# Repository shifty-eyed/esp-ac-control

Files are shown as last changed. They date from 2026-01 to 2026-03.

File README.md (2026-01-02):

## ESP32 AC Control – WiFi HTTP API + Thermostat Interface

This project controls an AC unit via an **ESP32-WROOM-32** board connected to a **proprietary wall thermostat**.  
The ESP32 exposes a **simple HTTP API** over WiFi and electrically **emulates the thermostat’s ON/OFF button** and **reads the thermostat’s LED status**.

- **HTTP API (port 80)**:
  - **`GET /status`** → returns JSON with AC status, current time, schedules, and webhook URL.
  - **`PUT /on`** → emulates a button press only if AC is currently OFF.
  - **`PUT /off`** → emulates a button press only if AC is currently ON.
  - **`PUT /ha-hook-url?value=<url>`** → configure Home Assistant webhook URL.
  - **`GET /time`** → returns current system time and sync status (JSON).
  - **`PUT /synctime`** → manually trigger NTP time synchronization.
  - **`GET /schedule`** → list all configured schedules (JSON).
  - **`PUT /schedule`** → create or update a schedule.
  - **`DELETE /schedule`** → delete a schedule by ID.
  - **`GET /journal`** → retrieve activity log with timestamps.
  - **`DELETE /journal`** → clear activity log.
  - **`GET /state-journal`** → retrieve AC state change history (CSV format).
  - **`DELETE /state-journal`** → clear state change history.

The project assumes:

- Thermostat **button voltage: 5 V DC**.
- Thermostat **LED sense node: ~0 V on, ~3 V off (DC, measured to thermostat ground)**.
- ESP32 is powered from a **separate 5 V USB power supply**, but **shares ground** with the thermostat electronics.

---

## Framework Choice

The recommended stack for this project is:

- **PlatformIO** (as the build system/IDE).
- **Arduino framework for ESP32**.

**Why Arduino + PlatformIO:**

- Very quick to bring up **WiFi** and an **HTTP server**.
- Lots of reference code and simple APIs (`WiFi.h`, `WebServer.h`).
- Good enough for this relatively small project.

You can later migrate to **ESP-IDF** if you need more control, but Arduino is ideal to get this working fast.

---

## Hardware Overview

- **ESP32 dev board** (e.g. ESP32-WROOM-32 DevKitC).
- **Separate USB 5 V supply** powering the ESP32 dev board.
- **One relay module** (e.g., 1-channel 5V relay module) to emulate the button press.
- Connection to thermostat:
  - **Two button wires** (momentary ON/OFF) - connected via relay contacts.
  - **Two LED wires** (indicating ON/OFF state) - connected to ESP32 GPIO for sensing.

> **Important:** There is **no galvanic isolation** between ESP32 and thermostat in this design.
> The relay provides electrical isolation for the button control, but the LED sense line shares a common ground.
> You accept the risk that sharing ground and interfacing directly may stress the thermostat electronics if its internal design is unusual.

---

## ESP32 Pin Assignment

- **Relay control output (ACTIVE LOW)**:
  - **`GPIO25`** – output (LOW = relay ON = button pressed, HIGH = relay OFF = button released)
- **Thermostat LED sense input (digital)**:
  - **`GPIO32`** – digital input (reads ~3V when AC is ON, ~0V when AC is OFF)

These pins avoid boot-strapping issues and are safe, general-purpose choices on ESP32-WROOM-32.

---

## Power and Grounding

- **ESP32 power:**
  - 5 V from **USB power supply** into ESP32 dev board.
  - The board’s onboard regulator provides **3.3 V** for the ESP32 and GPIO.
- **Thermostat power:**
  - Remains completely on its **own internal supply**.
- **Shared ground (required):**
  - Connect **ESP32 GND** to **thermostat ground**:
    - The thermostat ground is the **LED negative** line and usually one side of the button.

This common ground allows ESP32 GPIO voltages to be correctly referenced to the thermostat signals.

---

## Wiring – Button Emulation with Relay Module

Goal: When ESP32 `GPIO25` goes **LOW**, the relay activates and **closes the button contacts** (in parallel with the physical button), emulating a button press.

### 1. Identify button ground and signal

1. Power the thermostat as normal.
2. With a multimeter:
   - Black probe on the **LED negative** (this is thermostat ground).
   - Red probe on each of the two **button wires**.
3. You should see:
   - One button wire at ≈ **0 V** → this is **button ground side**.
   - The other at some positive voltage (around **5 V**) or varying when pressed → **button signal side**.

Keep the physical button connected; we simply add the relay contacts **in parallel**.

### 2. Relay module wiring

Use a standard **1-channel 5V relay module** (commonly available with opto-isolated input).

**Relay Module Connections:**

- **VCC** (relay module power):
  - Connect to **ESP32 5V** (VIN pin on dev board, powered from USB).

- **GND** (relay module ground):
  - Connect to **ESP32 GND**.

- **IN** (relay control signal):
  - Connect to **ESP32 `GPIO25`**.
  - Most relay modules are **ACTIVE LOW**: when GPIO25 is LOW, relay activates.

**Relay Contacts (to thermostat button):**

- **COM** (common terminal):
  - Connect to **button ground side** (the wire that measured ~0V).

- **NO** (normally open terminal):
  - Connect to **button signal side** (the wire that measured ~5V).

**Shared Ground:**

- Connect **thermostat ground** (LED negative wire) to **ESP32 GND**.
  - This common ground reference is necessary for the LED sense circuit to work correctly.

### How it works

- When `GPIO25` is **HIGH** → relay is **off**, button contacts are **open**, button behaves normally.
- When `GPIO25` is **LOW** → relay **activates**, NO contact **closes** to COM, **shorting the button signal to ground**, emulating a button press.

The ESP32 code drives GPIO25 LOW for 300ms to emulate a button press, then returns it HIGH to release.

---

## Wiring – LED Status to ESP32 (Digital Input)
TBD

### LED sense wiring (digital)
TBD

The 10 kΩ resistor limits current and provides protection for the GPIO pin.

## Software Sketch Outline (Arduino + PlatformIO)

This section intentionally left open so you can keep the software implementation in code files  
(`main.cpp`, etc.) rather than embedding it in the README.

---

## PlatformIO Quick Start

1. **Create project** in PlatformIO:
   - Board: **`esp32dev`** (or your specific ESP32 DevKit).
   - Framework: **Arduino**.
2. Implement your logic in `src/main.cpp` using the wiring and API description above.
3. Set your **WiFi credentials** in your code (`ssid` / `password` or similar).
4. Connect the ESP32 via USB.
5. In PlatformIO:
   - **Build** → **Upload** → **Monitor**.
6. Once running, note the **IP address** printed over serial.

Test from a PC on the same network:

```bash
# Check AC status (returns JSON with status, time, schedules, webhook URL)
curl http://<esp-ip>/status

# Turn AC on
curl -X PUT http://<esp-ip>/on

# Turn AC off
curl -X PUT http://<esp-ip>/off

# Configure Home Assistant webhook
curl -X PUT "http://<esp-ip>/ha-hook-url?value=http://<ha-ip>:8123/api/webhook/<webhook-id>"

# Create/update a schedule (turn AC on at 7:30 AM)
curl -X PUT "http://<esp-ip>/schedule?id=0&hour=7&minute=30&switch=1"

# Delete a schedule
curl -X DELETE "http://<esp-ip>/schedule?id=0"

# View activity journal
curl http://<esp-ip>/journal

# View state change history (CSV)
curl http://<esp-ip>/state-journal

# Clear journals
curl -X DELETE http://<esp-ip>/journal
curl -X DELETE http://<esp-ip>/state-journal
```

---

## Time Synchronization and Scheduling

The system includes **NTP time synchronization** and **persistent schedule management** to automatically control the AC at specific times.

### Time Synchronization

- **NTP Server**: `pool.ntp.org`
- **Timezone**: GMT-5 (Eastern US) – configurable in code
- **Sync Mode**: Manual only (no automatic re-sync)
- Initial sync attempted on boot; device continues to work even if sync fails

#### Time API Endpoints

**GET /time** – Get current system time

```bash
curl http://<esp-ip>/time
```

Response:
```json
{"time": "2025-11-25 14:30:00", "synced": true}
```

**PUT /synctime** – Manually trigger NTP sync

```bash
curl -X PUT http://<esp-ip>/synctime
```

Response:
```json
{"status": "syncing"}
```

### Schedule Management

Up to **16 schedules** (IDs 0-15) are stored persistently in **NVS (Non-Volatile Storage)** and survive ESP32 reboots.

Each schedule specifies:
- **id**: Schedule slot (0-15)
- **hour**: Hour of day (0-23)
- **minute**: Minute of hour (0-59)
- **switch**: Desired AC state (1 = turn on, 0 = turn off)

The system checks schedules every loop iteration and automatically triggers the AC when the scheduled time is reached.

#### Schedule API Endpoints

**GET /schedule** – List all schedules

```bash
curl http://<esp-ip>/schedule
```

Response:
```json
[
  {"id": 0, "hour": 7, "minute": 30, "switch": 1},
  {"id": 1, "hour": 22, "minute": 0, "switch": 0}
]
```

**PUT /schedule** – Create or update a schedule

```bash
# Turn AC ON at 7:30 AM
curl -X PUT "http://192.168.4.120/schedule?id=0&hour=7&minute=30&switch=1"

# Turn AC OFF at 10:00 PM (22:00)
curl -X PUT "http://192.168.4.120/schedule?id=1&hour=22&minute=0&switch=0"

```

Response:
```json
{"status": "ok", "id": 0}
```

**DELETE /schedule** – Delete a schedule

```bash
curl -X DELETE "http://<esp-ip>/schedule?id=0"
```

Response:
```json
{"status": "deleted", "id": 0}
```

#### Parameter Validation

- **id**: Must be 0-15
- **hour**: Must be 0-23 (24-hour format)
- **minute**: Must be 0-59
- **switch**: Must be 0 (off) or 1 (on)

Invalid parameters return HTTP 400 with error details in JSON.

### Schedule Behavior

- Schedules are checked every loop iteration (≈2ms)
- When a schedule time is reached, the system:
  1. Checks current AC state
  2. If AC is already in desired state, no action is taken
  3. If AC needs to change state, a button press is emulated
- Each schedule triggers only once per minute (prevents duplicate execution)
- Schedules persist through reboots via NVS storage

---

## Home Assistant Integration

The system includes **webhook integration** to automatically notify Home Assistant whenever the AC state changes.

### Configuring the Webhook

Set the Home Assistant webhook URL using the `/ha-hook-url` endpoint:

```bash
curl -X PUT "http://<esp-ip>/ha-hook-url?value=http://<ha-ip>:8123/api/webhook/<webhook-id>"
```

**Example:**
```bash
curl -X PUT "http://192.168.4.120/ha-hook-url?value=http://192.168.4.199:8123/api/webhook/ac_status_main"
```

The webhook URL is stored persistently in NVS and survives ESP32 reboots.

### Webhook Behavior

The ESP32 automatically sends an HTTP POST request to the configured webhook URL whenever the AC state changes:

- **When triggered:**
  - Manual API control via `/on` or `/off` endpoints
  - Scheduled events (when a schedule triggers a state change)
  - External state changes detected (someone uses the physical thermostat button)

- **Payload format (JSON):**
  ```json
  {"status":"on"}
  ```
  or
  ```json
  {"status":"off"}
  ```

- **HTTP timeout:** 5 seconds
- **Logging:** All webhook attempts are logged to the activity journal with HTTP response codes

### Checking Current Configuration

The configured webhook URL is included in the `/status` endpoint response:

```bash
curl http://<esp-ip>/status
```

Response includes:
```json
{
  "status": "1",
  "time": "2025-12-29 10:30:00",
  "schedules": [...],
  "ha_webhook": "http://192.168.4.199:8123/api/webhook/ac_status_main"
}
```

---

## External State Change Detection

The system continuously monitors the AC state to detect **external changes** that occur outside of the ESP32's control, such as someone manually pressing the physical thermostat button.

### How It Works

- **Monitoring interval:** Every 5 seconds
- **Detection method:** Compares current AC state (read from LED) against the last known state
- **Actions when external change detected:**
  1. Updates the internal state tracker
  2. Logs the state change to the state journal
  3. Sends a webhook notification to Home Assistant (if configured)

### Use Cases

- **Track manual overrides:** Know when someone uses the physical thermostat instead of the API
- **Synchronize state:** Keep Home Assistant and other systems synchronized even when the thermostat is manually controlled
- **Debugging:** Identify unexpected state changes or thermostat behavior
- **Analytics:** Build a complete history of all AC state changes regardless of source

### Example

If you turn on the AC using `/on`, the system knows it initiated the change. But if someone walks up and presses the physical button, the external state change detection will:
- Detect the change within 5 seconds
- Log it: `[2025-12-29 14:32:15] External state change detected`
- Record the timestamp and new state in the state journal
- Notify Home Assistant via webhook

This ensures complete visibility into all AC state changes, whether controlled by the API, schedules, or manual button presses.

---

## Activity Logging (Journal System)

The system includes two types of journals for tracking activity and debugging:

### 1. Activity Journal

A **circular buffer** that stores the most recent **200 events** with timestamps.

**What it logs:**
- Manual API requests (`/on`, `/off`)
- Schedule triggers and results
- Webhook POST attempts and HTTP response codes
- Configuration changes (webhook URL updates)
- External state changes detected

**Format:**
```
[YYYY-MM-DD HH:MM:SS] message
```

**Example output:**
```
[2025-12-29 07:30:00] Schedule #0 triggered: Turn ON
[2025-12-29 07:30:01] Schedule #0 result: Success from 0 retry
[2025-12-29 07:30:02] HA webhook: on -> HTTP 200
[2025-12-29 14:15:23] Manual turn OFF requested
[2025-12-29 14:15:24] Manual turn OFF result: Already there
```

**API Endpoints:**

```bash
# View activity journal
curl http://<esp-ip>/journal

# Clear activity journal
curl -X DELETE http://<esp-ip>/journal
```

### 2. State Journal

A **linear buffer** that stores up to **3000 state change records** for long-term analytics.

**What it logs:**
- Every AC state transition (ON→OFF or OFF→ON)
- Includes both API-initiated and externally-detected changes

**Format (CSV):**
```
timestamp,state
```

Where:
- `timestamp` = Unix timestamp (seconds since epoch)
- `state` = `1` (AC on) or `0` (AC off)

**Example output:**
```
1735473000,1
1735480200,0
1735494600,1
```

**API Endpoints:**

```bash
# View state journal (CSV format)
curl http://<esp-ip>/state-journal

# Clear state journal
curl -X DELETE http://<esp-ip>/state-journal
```

### Use Cases

- **Debugging:** Trace exactly what happened and when
- **Analytics:** Export state journal CSV for analysis (uptime statistics, usage patterns, etc.)
- **Monitoring:** Check recent activity via journal endpoint
- **Troubleshooting:** Identify why a schedule didn't trigger or why a state change failed

The activity journal is useful for real-time debugging with human-readable messages, while the state journal provides raw data perfect for importing into spreadsheets or data analysis tools.

---

## Safety Notes

- Double-check **voltages** with a multimeter before final wiring.
- Verify that the **thermostat ground point** you tie to ESP32 GND is correct and stable.
- Start with **short test pulses** and monitor for any unusual thermostat behavior (reboots, flicker, etc.).
- If at any point the thermostat behaves erratically, consider switching to a **relay or optocoupler-based design** for full isolation.

---

With this wiring and setup, you get a **simple WiFi-controlled AC switch** that mirrors the existing wall thermostat’s logic and state via a clean HTTP API.

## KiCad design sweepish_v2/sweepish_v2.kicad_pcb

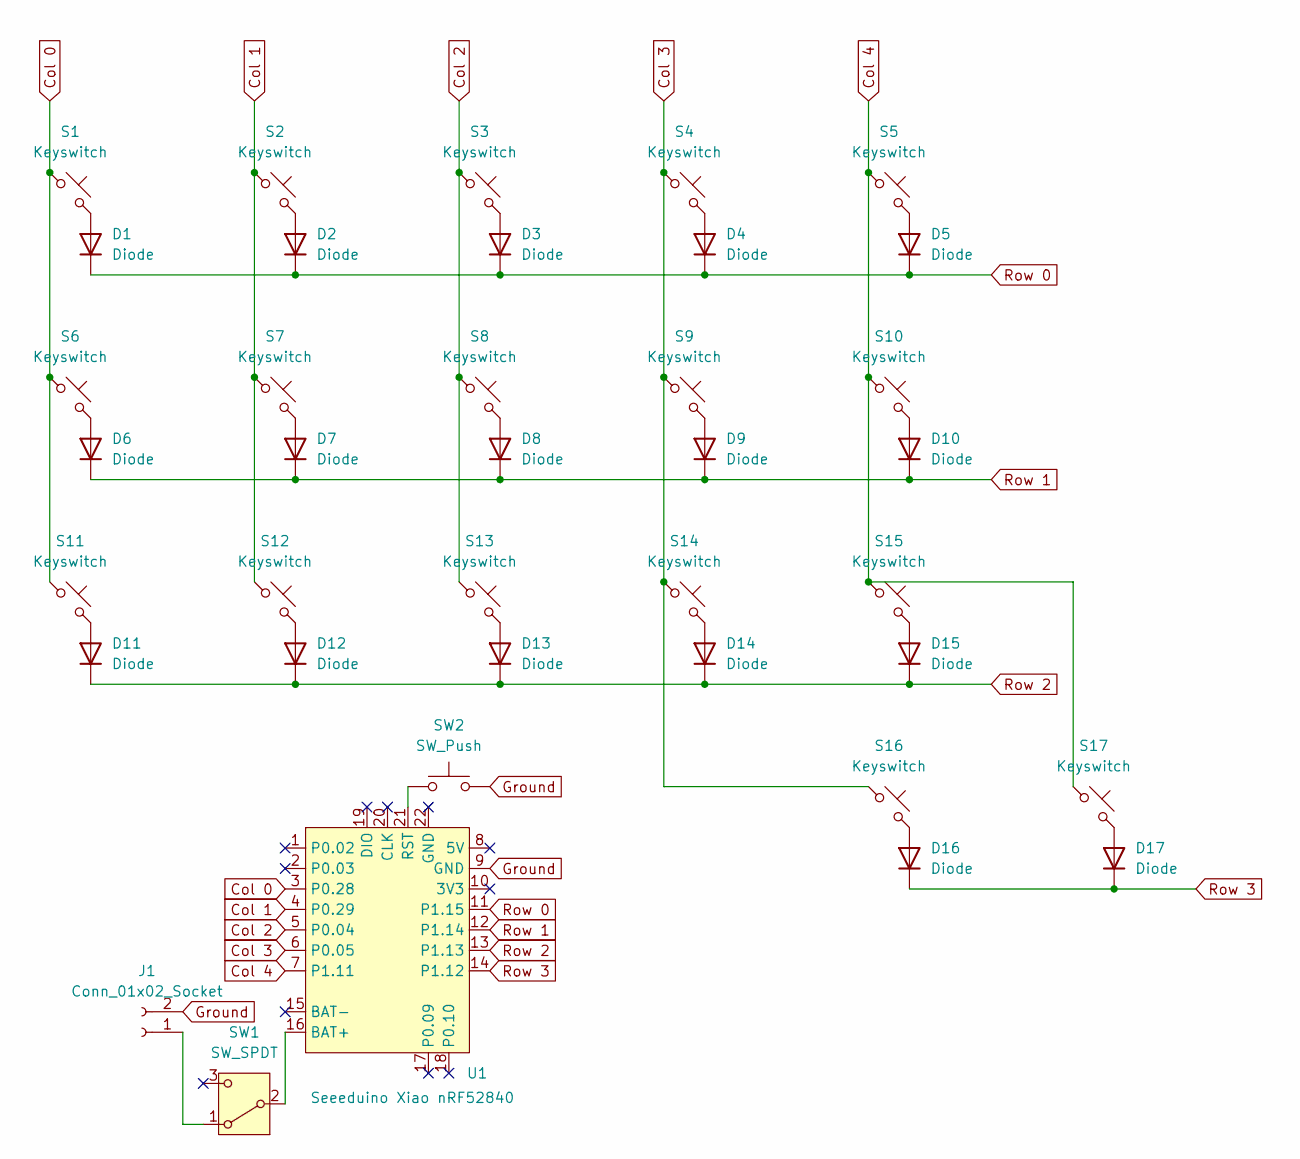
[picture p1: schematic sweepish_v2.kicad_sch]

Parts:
D1, D2, D3, D4, D5, D6, D7, D8, D9, D10, D11, D12, D13, D14, D15, D16, D17: Diode; Diode_SOD-123
J1: Conn_01x02_Socket; JST_PH_S2B-PH-SM4-TB_1x02-1MP_P2.00mm_Horizontal
S1, S2, S3, S4, S5, S6, S7, S8, S9, S10, S11, S12, S13, S14, S15, S16, S17: Keyswitch; Choc_V1_1.00u
SW1: SW_SPDT; SW_MSK12C02-HB
SW2: SW_Push; SW_T1A2QR
U1: Seeeduino Xiao nRF52840; Xiao_nRF52840_AC_Reflow

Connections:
Col 0: S1.1, S6.1, S11.1, U1.3 (P0.28)
Col 1: S2.1, S7.1, S12.1, U1.4 (P0.29)
Col 2: S3.1, S8.1, S13.1, U1.5 (P0.04)
Col 3: S4.1, S9.1, S14.1, S16.1, U1.6 (P0.05)
Col 4: S5.1, S10.1, S15.1, S17.1, U1.7 (P1.11)
Ground: J1.2, SW2.2, U1.9 (GND)
unnamed: D1.2 (A), S1.2
unnamed: D2.2 (A), S2.2
unnamed: D3.2 (A), S3.2
unnamed: D4.2 (A), S4.2
unnamed: D5.2 (A), S5.2
unnamed: D6.2 (A), S6.2
unnamed: D7.2 (A), S7.2
unnamed: D8.2 (A), S8.2
unnamed: D9.2 (A), S9.2
unnamed: D10.2 (A), S10.2
unnamed: D11.2 (A), S11.2
unnamed: D12.2 (A), S12.2
unnamed: D13.2 (A), S13.2
unnamed: D14.2 (A), S14.2
unnamed: D15.2 (A), S15.2
unnamed: D16.2 (A), S16.2
unnamed: D17.2 (A), S17.2
unnamed: J1.1, SW1.1 (A)
unnamed: SW1.2 (B), U1.16 (BAT+)
unnamed: SW2.1, U1.21 (RST)
Row 0: D1.1 (K), D2.1 (K), D3.1 (K), D4.1 (K), D5.1 (K), U1.11 (P1.15)
Row 1: D6.1 (K), D7.1 (K), D8.1 (K), D9.1 (K), D10.1 (K), U1.12 (P1.14)
Row 2: D11.1 (K), D12.1 (K), D13.1 (K), D14.1 (K), D15.1 (K), U1.13 (P1.13)
Row 3: D16.1 (K), D17.1 (K), U1.14 (P1.12)

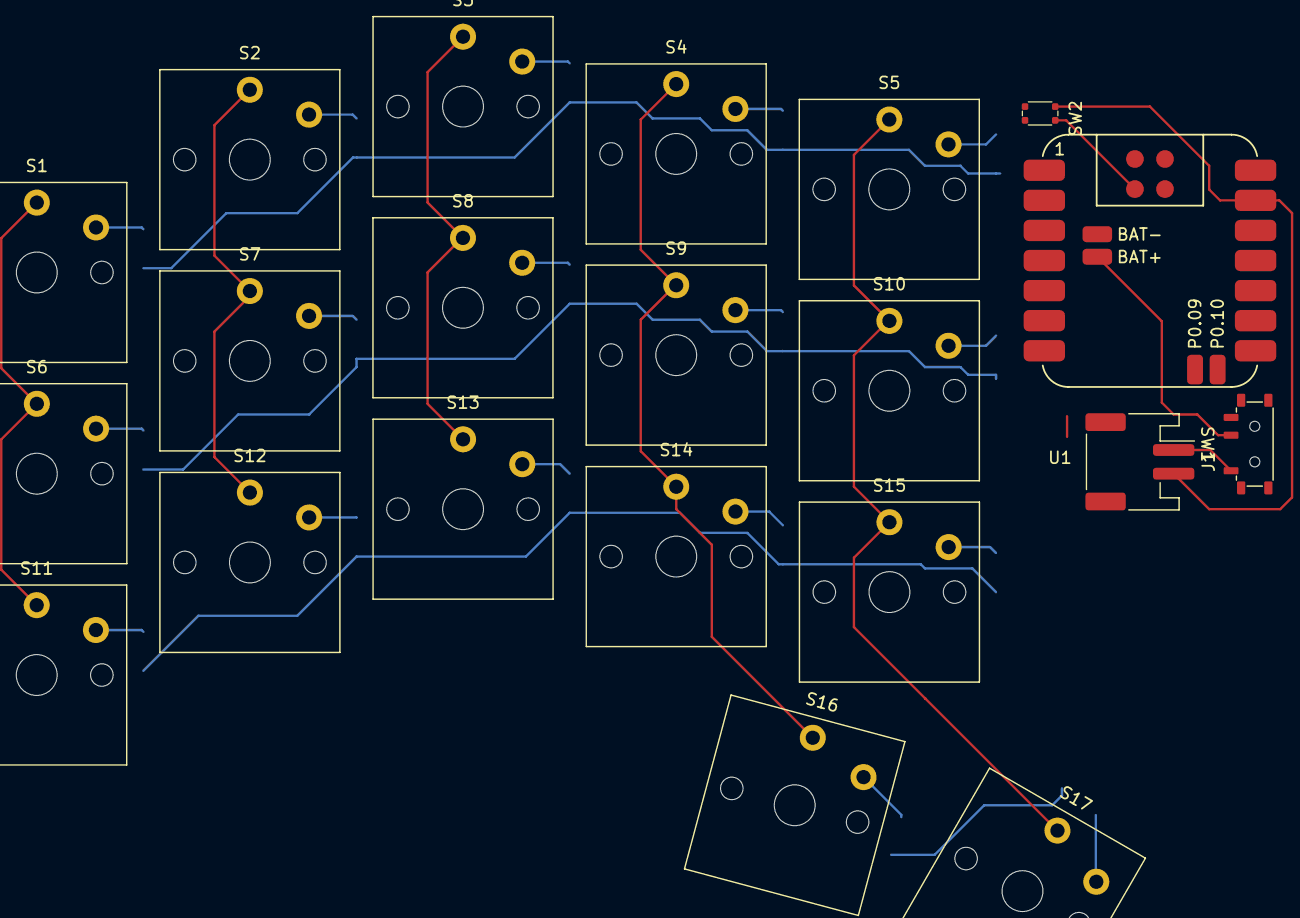
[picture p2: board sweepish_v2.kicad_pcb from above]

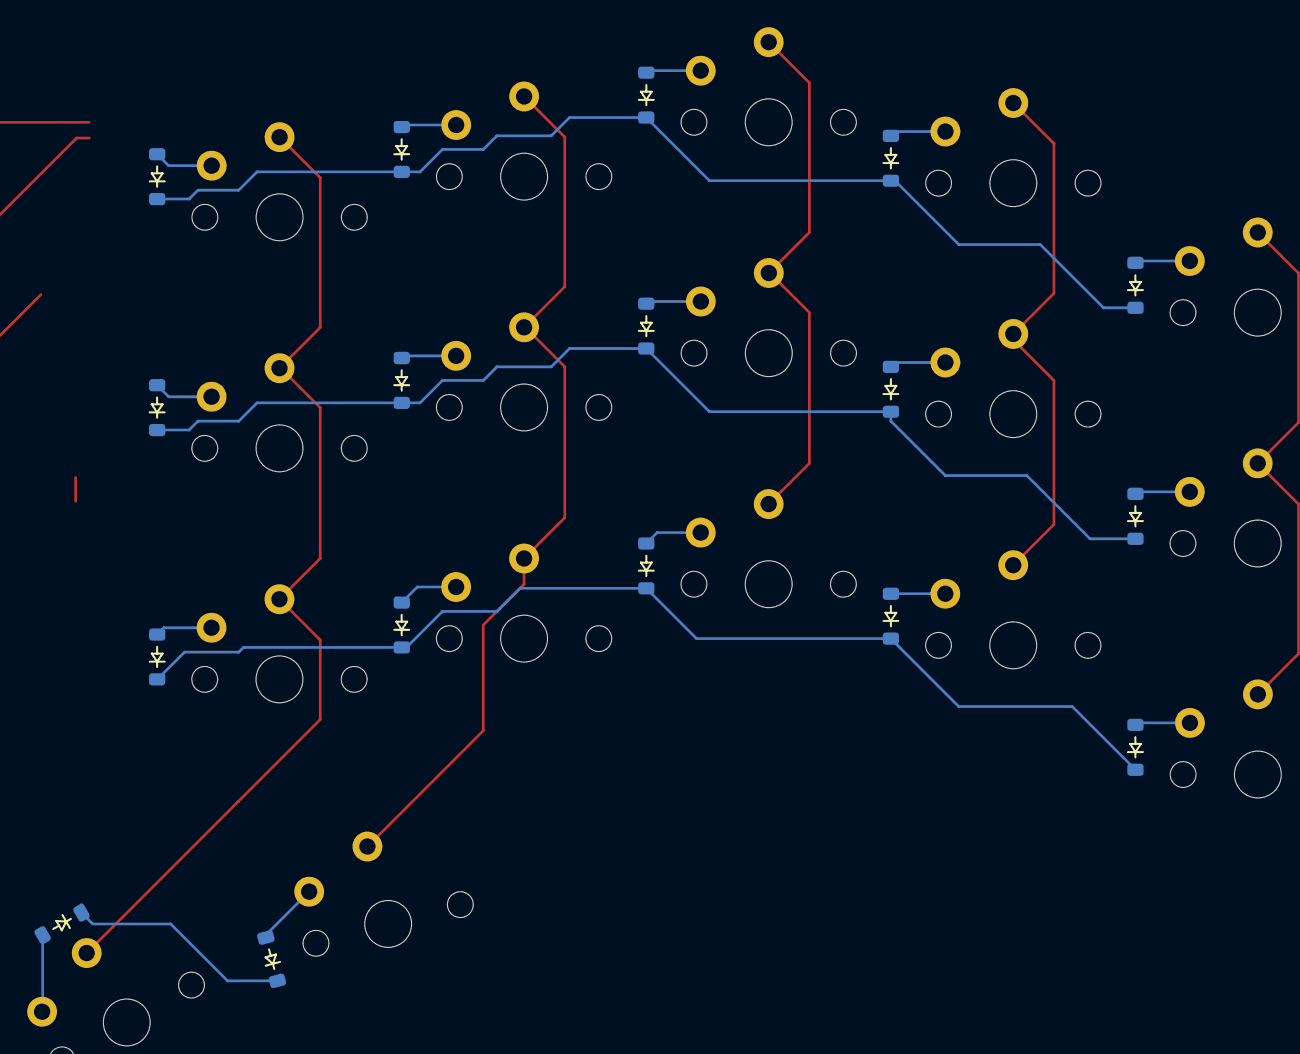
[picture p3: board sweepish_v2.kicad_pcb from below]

Board: 2 copper layers, 38 parts (17 on the bottom side), 30 nets.

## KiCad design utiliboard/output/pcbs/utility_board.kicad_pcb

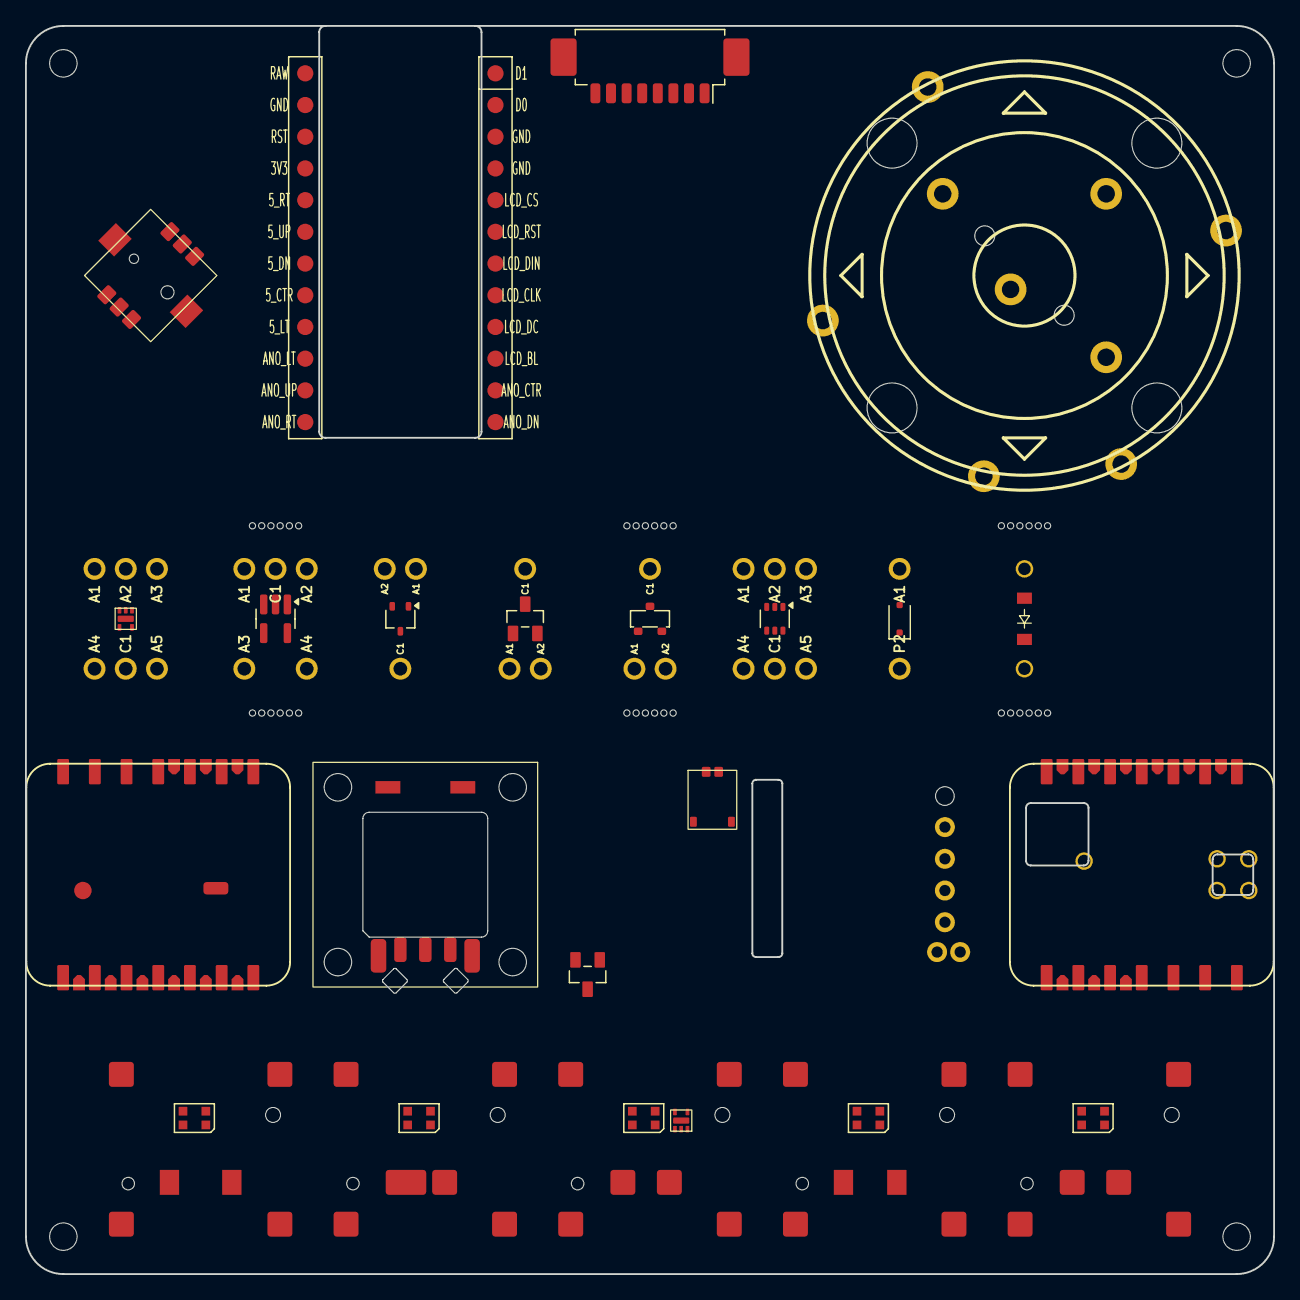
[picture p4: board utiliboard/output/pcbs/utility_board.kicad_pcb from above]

Board: 2 copper layers, 100.0 x 100.0 mm, 47 parts (0 on the bottom side), 76 nets, no tracks yet.

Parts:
CONN1: Molex_PicoBlade_53261-0871_1x08-1MP_P1.25mm_Horizontal
CONN2: Molex_Pico_EZMate_Plus_1x02
D1, D7: D_MMBD4148PLM
D2, D6: BAV70; BAV70 SOT23
D3: SOT-23
D4: D_SOD-323F
D5: diode_tht_sod123
H1, H2: mounting_hole_plated
LED1, LED2, LED3, LED4, LED5: LED_WS2812B-2020_PLCC4_2.0x2.0mm
MCU1: mcu_nice_nano
MDS1: SKRHADE010_naked
MH1, MH2, MH3, MH4: mounting_hole_npth
RE1: ENCODER_ANO
RE2: CKW12
S2, S3, S4, S5, S6: PG1316S
XX1, XX2, XX3, XX4, XX5, XX6: mousebites 2mm; mousebites_25mm
XX7, XX9, XX11, XX12, XX13, XX15, XX16: 5diode_Breakout_Holes
XX8: SC-74A-5_1.55x2.9mm_P0.95mm
XX10: SOT-323_SC-70
XX14: SOT-363_SC-70-6
XX17, XX18: xiao_plus_smd_prod

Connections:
1A1: D1.1, XX7.1
1A2: D1.2, XX7.2
1A3: D1.3, XX7.3
1A4: D1.4, XX7.4
1A5: D1.5, XX7.6
1C1: D1.6, XX7.5
2A1: XX8.1, XX9.3
2A2: XX8.3, XX9.1
2A3: XX8.4, XX9.4
2A4: XX8.5, XX9.5
2C1: XX8.2, XX9.2
3P1: XX10.1, XX11.1
3P2: XX10.2, XX11.2
3P3: XX10.3, XX11.3
3V3: CONN1.1, MCU1.21, XX17.12, XX18.12
4A1: D2.1, XX12.1
4A2: D2.2, XX12.2
4C1: D2.3, XX12.3
5A1: D3.1, XX13.1
5A2: D3.2, XX13.2
5C1: D3.3, XX13.3
5V: LED1.4, LED2.4, LED3.4, LED4.4, LED5.4, XX17.14, XX18.14
5_CTR: MCU1.17, MDS1.2
5_DN: MCU1.18, MDS1.3
5_LT: MCU1.16, MDS1.1
5_RT: MCU1.20, MDS1.6
5_UP: MCU1.19, MDS1.4
6P1: XX14.1, XX15.3
6P2: XX14.2, XX15.2
6P3: XX14.3, XX15.1
6P4: XX14.4, XX15.4
6P5: XX14.5, XX15.5
6P6: XX14.6, XX15.6
7P1: D4.2, XX16.1
7P2: D4.1, XX16.2
ANO_B: RE1.A, RE1.B
ANO_CTR: MCU1.11, RE1.S1
ANO_DN: MCU1.12, RE1.S2
ANO_LT: MCU1.15, RE1.S5
ANO_RT: MCU1.13, RE1.S3
ANO_UP: MCU1.14, RE1.S4
C0: RE2.S1, S2.1, XX17.19, XX18.19
C1: S3.1, XX17.6, XX18.6
C2: S4.1, XX17.21, XX18.21
C3: S5.1, XX17.9, XX18.9
C4: S6.1, XX17.22, XX18.22
GND: CONN1.2, CONN2.1, LED1.2, LED2.2, LED3.2, LED4.2, LED5.2, MCU1.3, MCU1.4, MCU1.23, MDS1.5, RE1.COM_A, RE1.COM_B, RE2.B, S3.3, S4.3, S5.3, S6.3, XX17.13, XX18.13, XX18.27
LCD_BL: CONN1.8, MCU1.10
LCD_CLK: CONN1.4, MCU1.8
LCD_CS: CONN1.5, MCU1.5
LCD_DC: CONN1.6, MCU1.9
LCD_DIN: CONN1.3, MCU1.7
LCD_RST: CONN1.7, MCU1.6
P0.02: XX17.1, XX18.1
P0.03: XX17.2, XX18.2
P0.15: XX17.15, XX18.15
P0.19: XX17.16, XX18.16
P0.28: XX17.3, XX18.3
P0.29: XX17.4, XX18.4
P0.31: XX17.20, XX18.20
P1.01: XX17.17, XX18.17
P1.15: XX17.11, XX18.11
R0: D7.6, XX17.7, XX18.7
R1: D6.3, XX17.8, XX18.8
RAW: CONN2.2, MCU1.24, XX17.28, XX18.28
RST: MCU1.22, XX17.26, XX18.26
ckw12_to: D6.1, RE2.S2
ckw_a: XX17.10, XX18.10
ckw_b: XX17.23, XX18.23
index_home: D7.1, S5.2
inner_home: D7.4, S6.2
middle_home: D7.2, S4.2
pinky_home: D7.5, S2.2
ring_home: D7.3, S3.2
scroll_a: XX17.18, XX18.18
scroll_b: XX17.5, XX18.5

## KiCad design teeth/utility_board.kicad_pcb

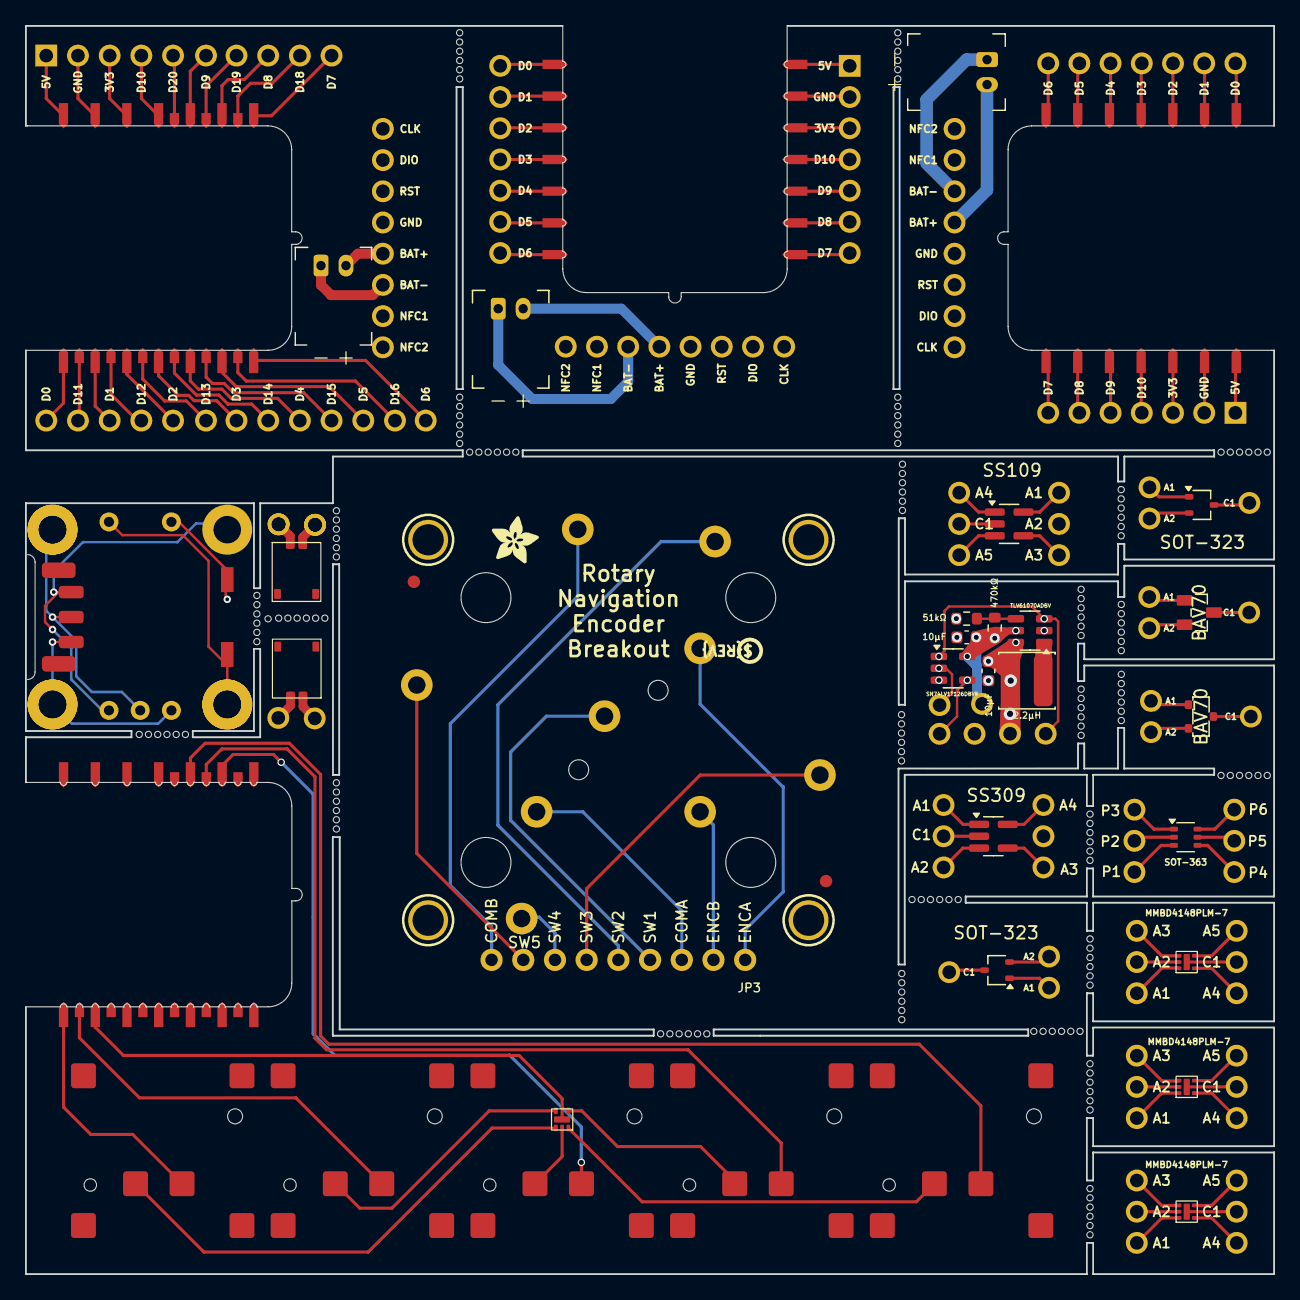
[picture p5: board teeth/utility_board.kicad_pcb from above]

Board: 2 copper layers, 100.1 x 100.0 mm, 54 parts (1 on the bottom side), 107 nets.

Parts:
C1, C2: 10μF; C_0603_1608Metric
CONN1, CONN1#2: Battery Connector; Molex_Pico_EZMate_Plus_1x02
D1, D2, D3, D8: D_MMBD4148PLM
D5: SOT-23
D6: BAV70; BAV70 SOT23
FID3, FID4: FIDUCIAL_1MM
J1, J2#2, J3, J4#2: xiao_plus_cutout
J1#2, J2, J3#2, J4: Conn_01x01_Pin; my_mount_hole_M2_pad
JP3: 1X09_ROUND_70
JST1, JST1#2, JST1#3: battery_connector_jst_ph_2
L1: 2.2μH; L_CJIANG_FTC404030S_4.1x4.1x3.0_SMD
MCU1, MCU2, MCU3: XIAO_Breakout_Holes
R1: 470kΩ; R_0603_1608Metric
R2: 51kΩ; R_0603_1608Metric
S1, S3, S5, S7, S9: PG1316S_Square_Pads
U1: TLV61070ADBV; SOT-23-6
U2: SN74LV1T126DBVR; SOT-23-5
U$25, U$27, U$29, U$30: MOUNTINGHOLE2.5; MOUNTINGHOLE_2.5_PLATED
U$32: ADAFRUIT_3.5MM
U$33: PCBFEAT-REV-040
X1: ENCODER_ANO
XX17, XX18, XX18#2, XX19, XX19#2, XX19#3, XX21, XX21#2, XX21#3, XX22: 5diode_Breakout_Holes

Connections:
1A1: D1.1, XX17.1
1A2: D1.2, XX17.2
1A3: D1.3, XX17.3
1A4: D1.4, XX17.4
1A5: D1.5, XX17.5
1C1: D1.6, XX17.6
2A1: D2.1, XX18.1
2A2: D2.2, XX18.2
2A3: D2.3, XX18.3
2A4: D2.4, XX18.4
2A5: D2.5, XX18.5
2C1: D2.6, XX18.6
3A1: D3.1, XX19.1
3A2: D3.2, XX19.2
3A3: D3.3, XX19.3
3A4: D3.4, XX19.4
3A5: D3.5, XX19.5
3C1: D3.6, XX19.6
3V3_a: J2#2.12, MCU1.12
3V3_b: J3.12, MCU2.12
3V3_c: J4#2.12, MCU3.12
5A1: D5.1, XX21#3.1
5A2: D5.2, XX21#3.2
5C1: D5.3, XX21#3.3
5V: C2.1, J1.14, R1.1, U1.5 (V_{OUT}), U2.5 (VCC)
5V_EN: U1.3 (EN), U2.1
5V_a: J2#2.14, MCU1.14
5V_b: J3.14, MCU2.14
5V_c: J4#2.14, MCU3.14
6A1: D6.1, XX22.1
6A2: D6.2, XX22.2
6C1: D6.3, XX22.3
BAT-: JST1#2.1, MCU1.29
BAT_a: CONN1.2, CONN1#2.2, JST1#2.2, MCU1.28
BOOST_FB: R1.2, R2.1, U1.4 (V_{FB})
BOOST_SW: L1.2, U1.1 (SW)
COMA: JP3.3, X1.COM_A
COMB: JP3.9, X1.COM_B
D0_a: J2#2.1, MCU1.1
D0_b: J3.1, MCU2.1
D0_c: J4#2.1, MCU3.1
D1_a: J2#2.2, MCU1.2
D1_b: J3.2, MCU2.2
D1_c: J4#2.2, MCU3.2
D2_a: J2#2.3, MCU1.3
D2_b: J3.3, MCU2.3
D2_c: J4#2.3, MCU3.3
D3_a: J2#2.4, MCU1.4
D3_b: J3.4, MCU2.4
D3_c: J4#2.4, MCU3.4
D4_a: J2#2.5, MCU1.5
D4_b: J3.5, MCU2.5
D4_c: J4#2.5, MCU3.5
D5_a: J2#2.6, MCU1.6
D5_b: J3.6, MCU2.6
D5_c: J4#2.6, MCU3.6
D6_a: J2#2.7, MCU1.7
D6_b: J3.7, MCU2.7
D6_c: J4#2.7, MCU3.7
D7_a: J2#2.8, MCU1.8
D7_b: J3.8, MCU2.8
D7_c: J4#2.8, MCU3.8
D8_a: J2#2.9, MCU1.9
D8_b: J3.9, MCU2.9
D8_c: J4#2.9, MCU3.9
D9_a: J2#2.10, MCU1.10
D9_b: J3.10, MCU2.10
D9_c: J4#2.10, MCU3.10
D10_a: J2#2.11, MCU1.11
D10_b: J3.11, MCU2.11
D10_c: J4#2.11, MCU3.11
D11_a: J2#2.15, MCU1.15
D12_a: J2#2.16, MCU1.16
D13_a: J2#2.17, MCU1.17
D14_a: J2#2.18, MCU1.18
D15_a: J2#2.19, MCU1.19
D15_b: JST1#3.2, MCU2.19
D15_c: JST1.2, MCU3.19
D16_a: J2#2.20, MCU1.20
D16_b: JST1#3.1, MCU2.20
D16_c: JST1.1, MCU3.20
D17_a: J2#2.21, MCU1.21
D18_a: J2#2.22, MCU1.22
D19_a: J2#2.23, MCU1.23
ENC_A: JP3.1, X1.A
ENC_B: JP3.2, X1.B
GND: C1.2, C2.2, CONN1.1, CONN1#2.1, J1.13, R2.2, U1.2 (GND), U2.3 (GND), XX19#2.6, XX19#3.2
GND_a: J2#2.13, MCU1.13
GND_b: J3.13, MCU2.13
GND_c: J4#2.13, MCU3.13
P0.02: J1.1, S1.2
P0.03: D8.6, J1.2
P0.15: J1.15, S3.2
P1.05: J1.22, S7.2
P1.13: J1.9, S5.2
P1.14: J1.10, S9.2
RAW: C1.1, L1.1, U1.6 (V_{IN})
SW1: JP3.4, X1.S1
SW2: JP3.5, X1.S2
SW3: JP3.6, X1.S3
SW4: JP3.7, X1.S4
SW5: JP3.8, X1.S5
index_home: D8.4, S7.1
inner_home: D8.1, S9.1
middle_home: D8.2, S5.1
pinky_home: D8.3, S1.1
ring_home: D8.5, S3.1

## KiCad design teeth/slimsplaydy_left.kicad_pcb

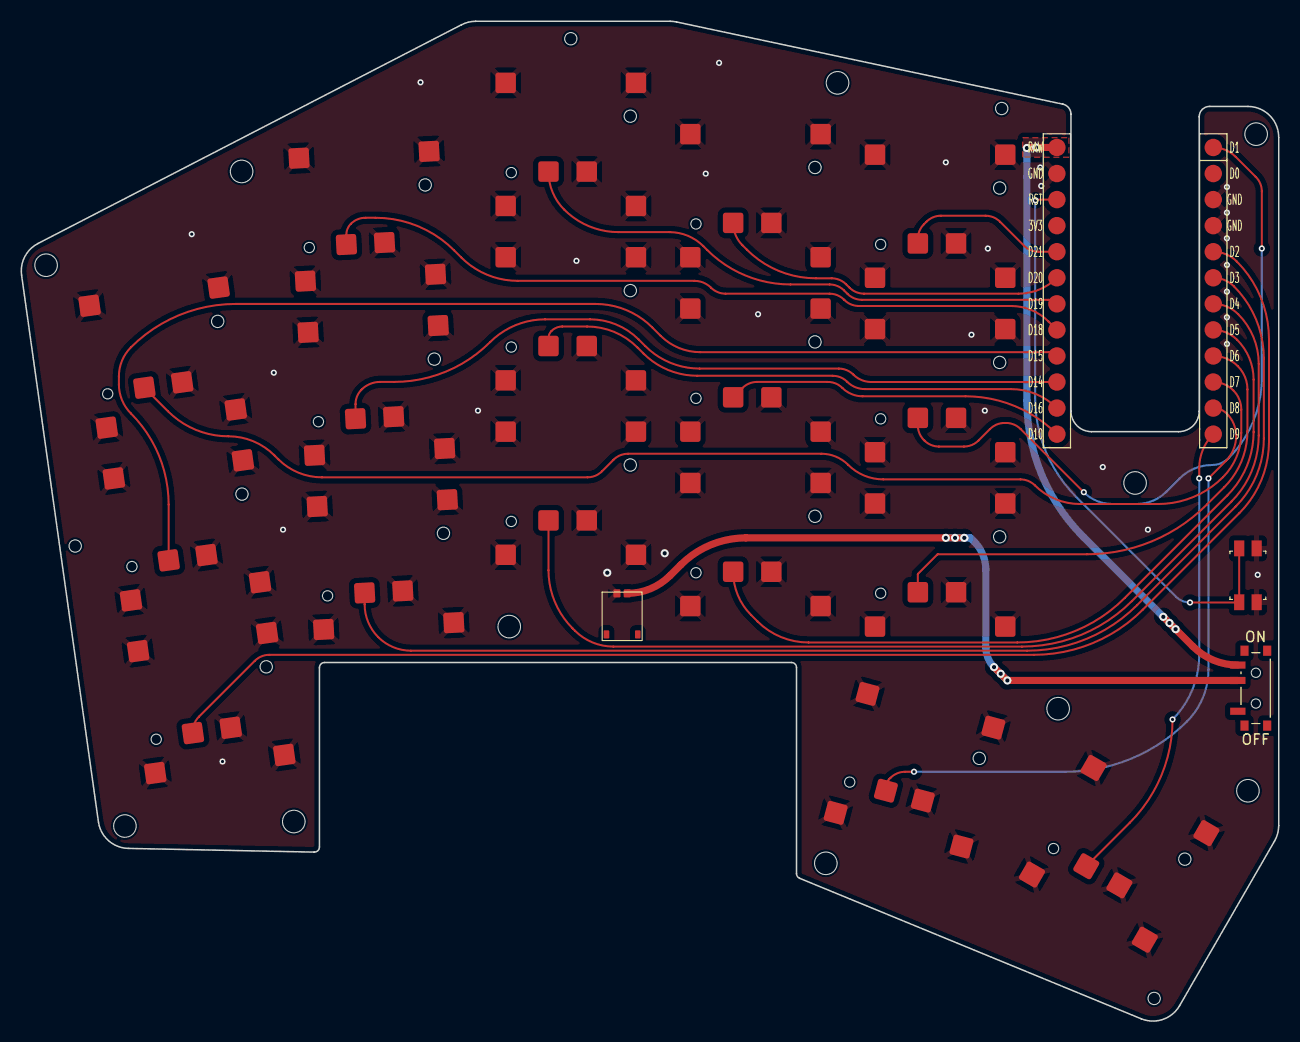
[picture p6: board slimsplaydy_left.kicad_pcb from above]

Board: 2 copper layers, 122.6 x 97.5 mm, 37 parts (1 on the bottom side), 21 nets.

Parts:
CONN1: Battery Connector; Molex_Pico_EZMate_Plus_1x02
MAG1: magsafe
MCU1: nice_nano; mcu_nice_nano
MH1, MH2, MH3, MH4, MH5, MH6, MH7, MH8, MH9, MH10, MH11, MH12, MH13, MH14, MH15: mounting_hole_npth
PWR1: Power SW; power_switch_smd_side
RST1: Reset SW; reset_switch_smd_side
S1, S2, S3, S4, S5, S6, S7, S8, S9, S10, S11, S12, S13, S14, S15, S16, S17: PG1316S

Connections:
BAT_P: CONN1.2, PWR1.2 (B)
GND: CONN1.1, MCU1.3 (GND), MCU1.4 (GND), MCU1.23 (GND), RST1.1, RST1.3, S1.2, S1.3 (B), S2.2, S2.3 (B), S3.2, S3.3 (B), S4.2, S4.3 (B), S5.2, S5.3 (B), S6.2, S6.3 (B), S7.2, S7.3 (B), S8.2, S8.3 (B), S9.2, S9.3 (B), S10.2, S10.3 (B), S11.2, S11.3 (B), S12.2, S12.3 (B), S13.2, S13.3 (B), S14.2, S14.3 (B), S15.2, S15.3 (B), S16.2, S16.3 (B), S17.2, S17.3 (B)
RAW: MCU1.24 (BAT+), PWR1.3 (C)
RST: MCU1.22 (RST), RST1.2, RST1.4
finger_index_bottom: MCU1.8 (P0.24), S10.1
finger_index_home: MCU1.13 (P0.09-LF), S11.1
finger_index_top: MCU1.19 (P0.29-LF), S12.1
finger_inner_bottom: MCU1.9 (P1.00), S13.1
finger_inner_home: MCU1.1 (P0.06), S14.1
finger_inner_top: MCU1.20 (P0.31-LF), S15.1
finger_middle_bottom: MCU1.7 (P0.22), S7.1
finger_middle_home: MCU1.14 (P0.10-LF), S8.1
finger_middle_top: MCU1.18 (P0.02-LF), S9.1
finger_pinky_bottom: MCU1.5 (P0.17), S1.1
finger_pinky_home: MCU1.16 (P1.13-LF), S2.1
finger_pinky_top: MCU1.10 (P0.11), S3.1
finger_ring_bottom: MCU1.6 (P0.20), S4.1
finger_ring_home: MCU1.15 (P1.11-LF), S5.1
finger_ring_top: MCU1.17 (P1.15-LF), S6.1
thumb_reachy_fan: MCU1.12 (P1.06-LF), S17.1
thumb_tucky_fan: MCU1.11 (P1.04-LF), S16.1

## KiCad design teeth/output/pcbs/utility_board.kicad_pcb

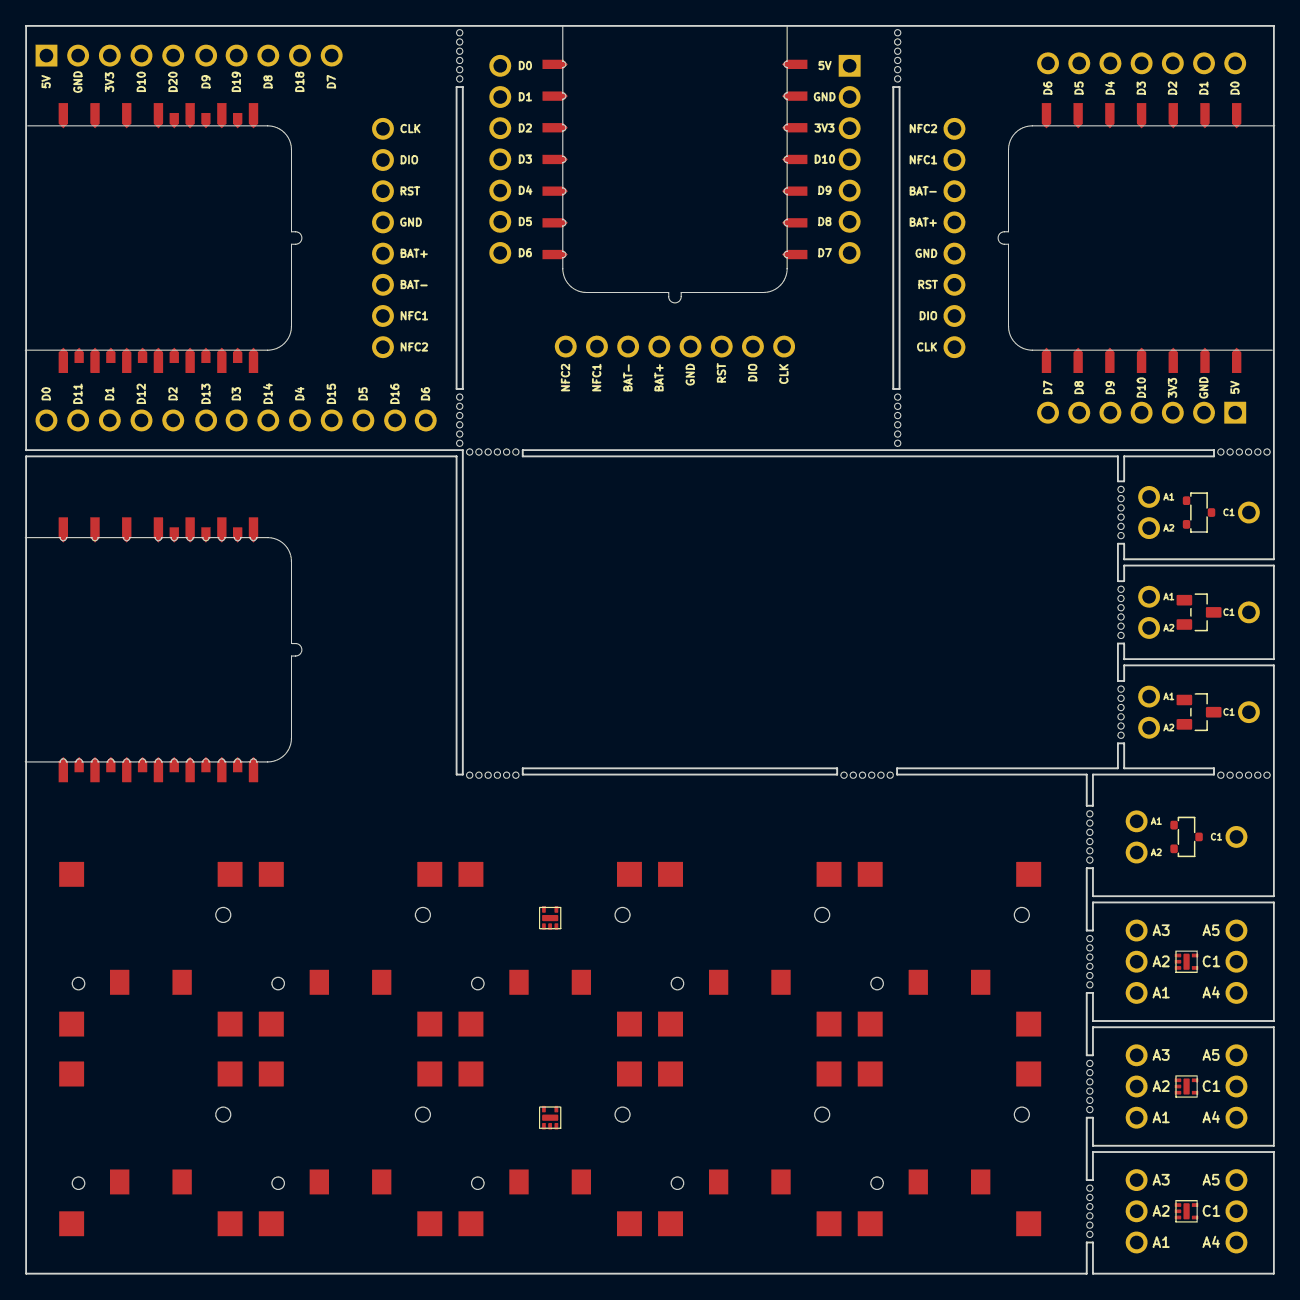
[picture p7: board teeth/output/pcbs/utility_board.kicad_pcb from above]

Board: 2 copper layers, 100.0 x 100.0 mm, 49 parts (0 on the bottom side), 98 nets, no tracks yet.

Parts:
D1, D2, D3, D8, D9: D_MMBD4148PLM
D4, D6: BAV70; BAV70 SOT23
D5, D7: SOT-23
J1, J2, J3, J4: xiao_plus_cutout
MCU1, MCU2, MCU3: XIAO_Breakout_Holes
S1, S2, S3, S4, S5, S6, S7, S8, S9, S10: CPG1316S01D02_mikeholscher
XX1, XX2, XX3, XX4, XX5, XX6, XX7, XX8, XX9, XX10, XX11, XX12, XX13, XX14, XX15, XX16: mousebites 2mm; mousebites_25mm
XX17, XX18, XX19, XX20, XX21, XX22, XX23: 5diode_Breakout_Holes

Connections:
1A1: D1.1, XX17.1
1A2: D1.2, XX17.2
1A3: D1.3, XX17.3
1A4: D1.4, XX17.4
1A5: D1.5, XX17.5
1C1: D1.6, XX17.6
2A1: D2.1, XX18.1
2A2: D2.2, XX18.2
2A3: D2.3, XX18.3
2A4: D2.4, XX18.4
2A5: D2.5, XX18.5
2C1: D2.6, XX18.6
3A1: D3.1, XX19.1
3A2: D3.2, XX19.2
3A3: D3.3, XX19.3
3A4: D3.4, XX19.4
3A5: D3.5, XX19.5
3C1: D3.6, XX19.6
3V3_a: J2.12, MCU1.12
3V3_b: J3.12, MCU2.12
3V3_c: J4.12, MCU3.12
4A1: D4.1, XX20.1
4A2: D4.2, XX20.2
4C1: D4.3, XX20.3
5A1: D5.1, XX21.1
5A2: D5.2, XX21.2
5C1: D5.3, XX21.3
5V_a: J2.14, MCU1.14
5V_b: J3.14, MCU2.14
5V_c: J4.14, MCU3.14
6A1: D6.1, XX22.1
6A2: D6.2, XX22.2
6C1: D6.3, XX22.3
7A1: D7.1, XX23.1
7A2: D7.2, XX23.2
7C1: D7.3, XX23.3
D0_a: J2.1, MCU1.1
D0_b: J3.1, MCU2.1
D0_c: J4.1, MCU3.1
D1_a: J2.2, MCU1.2
D1_b: J3.2, MCU2.2
D1_c: J4.2, MCU3.2
D2_a: J2.3, MCU1.3
D2_b: J3.3, MCU2.3
D2_c: J4.3, MCU3.3
D3_a: J2.4, MCU1.4
D3_b: J3.4, MCU2.4
D3_c: J4.4, MCU3.4
D4_a: J2.5, MCU1.5
D4_b: J3.5, MCU2.5
D4_c: J4.5, MCU3.5
D5_a: J2.6, MCU1.6
D5_b: J3.6, MCU2.6
D5_c: J4.6, MCU3.6
D6_a: J2.7, MCU1.7
D6_b: J3.7, MCU2.7
D6_c: J4.7, MCU3.7
D7_a: J2.8, MCU1.8
D7_b: J3.8, MCU2.8
D7_c: J4.8, MCU3.8
D8_a: J2.9, MCU1.9
D8_b: J3.9, MCU2.9
D8_c: J4.9, MCU3.9
D9_a: J2.10, MCU1.10
D9_b: J3.10, MCU2.10
D9_c: J4.10, MCU3.10
D10_a: J2.11, MCU1.11
D10_b: J3.11, MCU2.11
D10_c: J4.11, MCU3.11
D11_a: J2.15, MCU1.15
D12_a: J2.16, MCU1.16
D13_a: J2.17, MCU1.17
D14_a: J2.18, MCU1.18
D15_a: J2.19, MCU1.19
D16_a: J2.20, MCU1.20
D17_a: J2.21, MCU1.21
D18_a: J2.22, MCU1.22
D19_a: J2.23, MCU1.23
GND_a: J2.13, MCU1.13
GND_b: J3.13, MCU2.13
GND_c: J4.13, MCU3.13
P0.02: J1.1, S1.2, S2.2
P0.03: D8.6, J1.2
P0.15: J1.15, S3.2, S4.2
P1.03: D9.6, J1.21
P1.05: J1.22, S7.2, S8.2
P1.13: J1.9, S5.2, S6.2
P1.14: J1.10, S9.2, S10.2
index_home: D8.1, S7.1
index_top: D9.1, S8.1
inner_home: D8.4, S9.1
inner_top: D9.4, S10.1
middle_home: D8.2, S5.1
middle_top: D9.2, S6.1
pinky_home: D8.5, S1.1
pinky_top: D9.5, S2.1
ring_home: D8.3, S3.1
ring_top: D9.3, S4.1

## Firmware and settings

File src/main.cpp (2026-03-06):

/*
 * ESP32 AC Control - WiFi HTTP API for Thermostat Interface
 * 
 * Hardware connections:
 *   - GPIO25: Relay control (ACTIVE LOW - LOW=ON, HIGH=OFF)
 *   - GPIO32: LED sense input (digital read, 3V when AC on, 0V when off)
 *   - VIN: Relay module power
 *   - GND: Shared ground
 * 
 * HTTP API:
 *   GET  /status  → returns "1" (AC on) or "0" (AC off)
 *   PUT  /on      → turns AC on if currently off
 *   PUT  /off     → turns AC off if currently on
 */

#include <Arduino.h>
#include <WiFi.h>
#include <WebServer.h>
#include <HTTPClient.h>
#include <time.h>
#include <esp_sntp.h>
#include <Preferences.h>

#include "LedSense.h"

// Time configuration
const char* NTP_SERVER = "pool.ntp.org";
const long  GMT_OFFSET_SEC = -5 * 3600;      // GMT-5 (Eastern US)
const int   DAYLIGHT_OFFSET_SEC = 0;

// Schedule structure
struct Schedule {
  int id;
  int hour;
  int minute;
  int switchState;  // 1 = turn on, 0 = turn off
  bool executed;
  bool valid;       // true if schedule slot is populated
};

Schedule schedules[16];
Preferences preferences;
String haWebhookUrl = "";

bool lastKnownAcState = false;
unsigned long lastStateCheckMillis = 0;
const unsigned long STATE_CHECK_INTERVAL = 5000;

unsigned long lastWiFiCheckMillis = 0;
const unsigned long WIFI_CHECK_INTERVAL = 30000;

// Journal (in-memory log)
const int JOURNAL_MAX_LINES = 200;
String journal[JOURNAL_MAX_LINES];
int journalCount = 0;
int journalIndex = 0;  // Circular buffer index

struct StateChangeRecord {
  unsigned long timestamp;
  bool state;
};

const int STATE_JOURNAL_MAX_RECORDS = 3000;
StateChangeRecord stateJournal[STATE_JOURNAL_MAX_RECORDS];
int stateJournalCount = 0;

const char* WIFI_SSID     = "imenilenina-bistro";
const char* WIFI_PASSWORD = "10101010";

const int HTTP_PORT = 80;

const int BUTTON_PIN    = 25;
const int LED_SENSE_PIN = 32;

const int BUTTON_PRESS_DURATION = 300;

WebServer server(HTTP_PORT);

// LED sense is encapsulated to keep signal filtering/polarity isolated.
static LedSense ledSence;

static inline bool isAcOn() {
  return ledSence.isOn();
}

// ========== Journal Functions ==========

void addToJournal(String message) {
  struct tm timeinfo;
  String timestamp;

  if (getLocalTime(&timeinfo)) {
    char timeStr[20];
    strftime(timeStr, sizeof(timeStr), "%Y-%m-%d %H:%M:%S", &timeinfo);
    timestamp = String(timeStr);
  } else {
    timestamp = "NO-TIME";
  }

  journal[journalIndex] = "[" + timestamp + "] " + message;
  journalIndex = (journalIndex + 1) % JOURNAL_MAX_LINES;

  if (journalCount < JOURNAL_MAX_LINES) {
    journalCount++;
  }

  Serial.println("[JOURNAL] " + message);
}

void clearJournal() {
  journalCount = 0;
  journalIndex = 0;
  Serial.println("[JOURNAL] Cleared");
}

void addToStateJournal(bool state) {
  struct tm timeinfo;
  unsigned long timestamp = 0;

  if (getLocalTime(&timeinfo)) {
    timestamp = mktime(&timeinfo);
  }

  stateJournal[stateJournalCount].timestamp = timestamp;
  stateJournal[stateJournalCount].state = state;
  if (stateJournalCount < STATE_JOURNAL_MAX_RECORDS - 1) {
    stateJournalCount++;
  }
}

void clearStateJournal() {
  stateJournalCount = 0;
}

void initGPIO() {
  pinMode(BUTTON_PIN, OUTPUT);
  digitalWrite(BUTTON_PIN, LOW); 
  pinMode(LED_SENSE_PIN, INPUT_PULLUP);
}

void sendHomeAssistantWebhook(bool acState) {
  if (haWebhookUrl == "" || haWebhookUrl.length() == 0) {
    return;
  }
  if (WiFi.status() != WL_CONNECTED) {
    addToJournal("HA webhook skipped: WiFi not connected");
    return;
  }

  HTTPClient http;
  http.begin(haWebhookUrl);
  http.addHeader("Content-Type", "application/json");
  http.setTimeout(5000);

  String payload = "{\"status\":\"" + String(acState ? "on" : "off") + "\"}";

  int httpCode = http.POST(payload);

  String logMsg = "HA webhook: " + String(acState ? "on" : "off");
  if (httpCode > 0) {
    logMsg += " -> HTTP " + String(httpCode);
  } else {
    logMsg += " -> FAILED: " + http.errorToString(httpCode);
  }
  addToJournal(logMsg);

  http.end();
}

String setOn(bool desiredState) {
  const int maxAttempts = 5;
  for (int attempt = 0; attempt < maxAttempts; attempt++) {
    if (isAcOn() == desiredState) {
      if (attempt == 0) {
        return "Already there\n";
      } else {
        return "Success from " + String(attempt) + " retry\n";
      }
    }

    digitalWrite(BUTTON_PIN, HIGH);
    ledSence.wait(BUTTON_PRESS_DURATION);
    digitalWrite(BUTTON_PIN, LOW);
    ledSence.wait(500);
    if (isAcOn() != desiredState) {
      ledSence.wait(1500);
    }
  }

  return "Failed after " + String(maxAttempts) + " retries\n";
}

// ========== NVS Schedule Storage Functions ==========

void loadSchedulesFromNVS() {
  preferences.begin("schedules", false);  // false = read/write mode
  
  Serial.println("[NVS] Loading schedules from storage...");
  int loadedCount = 0;
  
  for (int i = 0; i < 16; i++) {
    String keyValid = "sch" + String(i) + "_v";
    bool isValid = preferences.getBool(keyValid.c_str(), false);
    
    if (isValid) {
      String keyHour = "sch" + String(i) + "_h";
      String keyMin = "sch" + String(i) + "_m";
      String keySwitch = "sch" + String(i) + "_s";
      
      schedules[i].id = i;
      schedules[i].hour = preferences.getInt(keyHour.c_str(), 0);
      schedules[i].minute = preferences.getInt(keyMin.c_str(), 0);
      schedules[i].switchState = preferences.getInt(keySwitch.c_str(), 0);
      schedules[i].executed = false;
      schedules[i].valid = true;
      
      loadedCount++;
      Serial.print("[NVS] Loaded schedule ");
      Serial.print(i);
      Serial.print(": ");
      Serial.print(schedules[i].hour);
      Serial.print(":");
      if (schedules[i].minute < 10) Serial.print("0");
      Serial.print(schedules[i].minute);
      Serial.print(" switch=");
      Serial.println(schedules[i].switchState);
    } else {
      schedules[i].valid = false;
      schedules[i].executed = false;
    }
  }
  
  Serial.print("[NVS] Loaded ");
  Serial.print(loadedCount);
  Serial.println(" schedules");
  
  preferences.end();
}

void loadWebhookUrlFromNVS() {
  preferences.begin("config", false);
  haWebhookUrl = preferences.getString("ha_webhook", "");
  preferences.end();

  if (haWebhookUrl.length() > 0) {
    Serial.print("[NVS] Loaded webhook URL: ");
    Serial.println(haWebhookUrl);
  }
}

void saveScheduleToNVS(int id) {
  if (id < 0 || id >= 16) return;
  
  preferences.begin("schedules", false);
  
  String keyValid = "sch" + String(id) + "_v";
  String keyHour = "sch" + String(id) + "_h";
  String keyMin = "sch" + String(id) + "_m";
  String keySwitch = "sch" + String(id) + "_s";
  
  preferences.putBool(keyValid.c_str(), schedules[id].valid);
  preferences.putInt(keyHour.c_str(), schedules[id].hour);
  preferences.putInt(keyMin.c_str(), schedules[id].minute);
  preferences.putInt(keySwitch.c_str(), schedules[id].switchState);
  
  Serial.print("[NVS] Saved schedule ");
  Serial.println(id);
  
  preferences.end();
}

void deleteScheduleFromNVS(int id) {
  if (id < 0 || id >= 16) return;
  
  preferences.begin("schedules", false);
  
  String keyValid = "sch" + String(id) + "_v";
  preferences.putBool(keyValid.c_str(), false);
  
  Serial.print("[NVS] Deleted schedule ");
  Serial.println(id);
  
  preferences.end();
  
  schedules[id].valid = false;
  schedules[id].executed = false;
}

void saveWebhookUrlToNVS(String url) {
  preferences.begin("config", false);
  preferences.putString("ha_webhook", url);
  preferences.end();
  haWebhookUrl = url;

  Serial.print("[NVS] Saved webhook URL: ");
  Serial.println(url);
}

// ========== Time Synchronization Functions ==========

void initTime() {
  Serial.println("[TIME] Initializing NTP time sync...");
  
  // Configure for manual sync only (no automatic re-sync)
  sntp_set_sync_mode(SNTP_SYNC_MODE_IMMED);
  
  // Configure time with NTP server
  configTime(GMT_OFFSET_SEC, DAYLIGHT_OFFSET_SEC, NTP_SERVER);
}

void manualSyncTime() {
  Serial.println("[TIME] Manual sync requested...");
  sntp_restart();
}


// ========== Schedule Management Functions ==========

bool isScheduleValid(int id) {
  if (id < 0 || id >= 16) return false;
  return schedules[id].valid;
}

void checkWiFiConnection() {
  unsigned long currentMillis = millis();
  if (currentMillis - lastWiFiCheckMillis < WIFI_CHECK_INTERVAL) return;
  lastWiFiCheckMillis = currentMillis;

  if (WiFi.status() != WL_CONNECTED) {
    Serial.println("[WiFi] Disconnected - reconnecting...");
    WiFi.reconnect();
  }
}

void checkForExternalStateChange() {
  unsigned long currentMillis = millis();

  if (currentMillis - lastStateCheckMillis >= STATE_CHECK_INTERVAL) {
    lastStateCheckMillis = currentMillis;

    bool currentAcState = isAcOn();

    if (currentAcState != lastKnownAcState) {
          lastKnownAcState = currentAcState;
          addToStateJournal(currentAcState);

          sendHomeAssistantWebhook(currentAcState);
    }
  }
}

void checkSchedules() {
  struct tm timeinfo;
  if (!getLocalTime(&timeinfo)) {
    return;
  }

  int currentHour = timeinfo.tm_hour;
  int currentMinute = timeinfo.tm_min;

  for (int i = 0; i < 16; i++) {
    if (!schedules[i].valid) continue;

    // Check if current time matches schedule
    if (schedules[i].hour == currentHour &&
        schedules[i].minute == currentMinute &&
        !schedules[i].executed) {

      schedules[i].executed = true;

      String action = (schedules[i].switchState == 1) ? "ON" : "OFF";
      String logMsg = "Schedule #" + String(i) + " triggered: Turn " + action;
      addToJournal(logMsg);

      String result = setOn(schedules[i].switchState == 1);
      addToJournal("Schedule #" + String(i) + " result: " + result);
    }

    // Reset executed flag when minute changes
    if (schedules[i].minute != currentMinute) {
      schedules[i].executed = false;
    }
  }
}


void handleStatus() {
  bool acOn = isAcOn();

  // Build combined JSON response
  String response = "{";

  // 1. AC Status
  response += "\"status\":\"";
  response += acOn ? "1" : "0";
  response += "\",";

  // 2. Time Info
  struct tm timeinfo;
  if (getLocalTime(&timeinfo)) {
    char timeStr[64];
    strftime(timeStr, sizeof(timeStr), "%Y-%m-%d %H:%M:%S", &timeinfo);

    response += "\"time\":\"";
    response += timeStr;
    response += "\",";
  } else {
    response += "\"time\":null,";
  }

  // 3. Schedules
  response += "\"schedules\":[";
  bool first = true;
  for (int i = 0; i < 16; i++) {
    if (schedules[i].valid) {
      if (!first) response += ",";
      first = false;

      response += "{\"id\":";
      response += i;
      response += ",\"hour\":";
      response += schedules[i].hour;
      response += ",\"minute\":";
      response += schedules[i].minute;
      response += ",\"switch\":";
      response += schedules[i].switchState;
      response += "}";
    }
  }
  response += "],";
  response += "\"ha_webhook\":\"" + haWebhookUrl + "\"";
  response += "}\n";

  server.send(200, "application/json", response);
}

void handleOn() {
  addToJournal("Manual turn ON requested");
  String result = setOn(true);
  addToJournal("Manual turn ON result: " + result);
  server.send(200, "text/plain", result);
}

void handleOff() {
  addToJournal("Manual turn OFF requested");
  String result = setOn(false);
  addToJournal("Manual turn OFF result: " + result);
  server.send(200, "text/plain", result);
}

void handleSetWebhook() {
  if (!server.hasArg("value")) {
    server.send(400, "text/plain", "Missing 'value' parameter\n");
    return;
  }

  String url = server.arg("value");
  saveWebhookUrlToNVS(url);
  addToJournal("HA webhook URL updated");

  server.send(200, "text/plain", "Webhook URL updated: " + url + "\n");
}

void handleNotFound() {
  String message = "Not Found\n\n";
  message += "Available endpoints:\n";
  message += "  GET  /status\n";
  message += "  PUT  /on\n";
  message += "  PUT  /off\n";
  message += "  PUT  /synctime\n";
  message += "  PUT  /schedule?id=X&hour=H&minute=M&switch=S\n";
  message += "  DELETE /schedule?id=X\n";
  message += "  GET  /journal\n";
  message += "  DELETE /journal\n";
  message += "  GET  /state-journal\n";
  message += "  DELETE /state-journal\n";

  server.send(404, "text/plain", message);
}

// ========== New HTTP Endpoint Handlers ==========

void handleGetJournal() {
  String response = "";

  int startIdx = (journalCount < JOURNAL_MAX_LINES) ? 0 : journalIndex;

  for (int i = 0; i < journalCount; i++) {
    int idx = (startIdx + i) % JOURNAL_MAX_LINES;
    response += journal[idx];
    response += "\n";
  }
  server.send(200, "text/plain", response);
}

void handleDeleteJournal() {
  clearJournal();
  server.send(200, "application/json", "{\"status\": \"cleared\"}\n");
}

void handleGetStateJournal() {
  String response = "";

  for (int i = 0; i < stateJournalCount; i++) {
    response += stateJournal[i].timestamp;
    response += ",";
    response += stateJournal[i].state ? "1" : "0";
    response += "\n";
  }

  server.send(200, "text/plain", response);
}

void handleDeleteStateJournal() {
  clearStateJournal();
  server.send(200, "application/json", "{\"status\": \"cleared\"}\n");
}

void handleSyncTime() {
  if (WiFi.status() != WL_CONNECTED) {
    server.send(503, "application/json", "{\"error\": \"WiFi not connected\"}\n");
    return;
  }

  manualSyncTime();
  server.send(200, "application/json", "{\"status\": \"syncing\"}\n");
}

void handlePutSchedule() {
  if (!server.hasArg("id") || !server.hasArg("hour") || 
      !server.hasArg("minute") || !server.hasArg("switch")) {
    server.send(400, "application/json", 
                "{\"error\": \"Missing parameters. Required: id, hour, minute, switch\"}\n");
    return;
  }
  
  int id = server.arg("id").toInt();
  int hour = server.arg("hour").toInt();
  int minute = server.arg("minute").toInt();
  int switchState = server.arg("switch").toInt();
  
  if (id < 0 || id >= 16) {
    server.send(400, "application/json", "{\"error\": \"id must be 0-15\"}\n");
    return;
  }
  if (hour < 0 || hour > 23) {
    server.send(400, "application/json", "{\"error\": \"hour must be 0-23\"}\n");
    return;
  }
  if (minute < 0 || minute > 59) {
    server.send(400, "application/json", "{\"error\": \"minute must be 0-59\"}\n");
    return;
  }
  if (switchState != 0 && switchState != 1) {
    server.send(400, "application/json", "{\"error\": \"switch must be 0 or 1\"}\n");
    return;
  }
  
  schedules[id].id = id;
  schedules[id].hour = hour;
  schedules[id].minute = minute;
  schedules[id].switchState = switchState;
  schedules[id].executed = false;
  schedules[id].valid = true;
  
  saveScheduleToNVS(id);
  
  String response = "{\"status\": \"ok\", \"id\": ";
  response += id;
  response += "}\n";
  
  server.send(200, "application/json", response);
}

void handleDeleteSchedule() {
  if (!server.hasArg("id")) {
    server.send(400, "application/json", "{\"error\": \"Missing id parameter\"}\n");
    return;
  }
  
  int id = server.arg("id").toInt();
  
  if (id < 0 || id >= 16) {
    server.send(400, "application/json", "{\"error\": \"id must be 0-15\"}\n");
    return;
  }
  
  if (!schedules[id].valid) {
    server.send(404, "application/json", "{\"error\": \"Schedule not found\"}\n");
    return;
  }
  
  deleteScheduleFromNVS(id);
  
  String response = "{\"status\": \"deleted\", \"id\": ";
  response += id;
  response += "}\n";
  
  server.send(200, "application/json", response);
}

void setup() {
  Serial.begin(115200);
  delay(100);
  
  initGPIO();
  ledSence.begin(LED_SENSE_PIN);

  loadSchedulesFromNVS();
  loadWebhookUrlFromNVS();
  
  WiFi.mode(WIFI_STA);
  WiFi.setAutoReconnect(true);
  WiFi.begin(WIFI_SSID, WIFI_PASSWORD);

  int attempts = 0;
  while (WiFi.status() != WL_CONNECTED) {
    delay(500);
    Serial.print(".");
    attempts++;

    if (attempts > 60) {  // 30 seconds timeout
      Serial.println();
      Serial.println("[WiFi] Initial connect timeout - will retry in background.");
      break;
    }
  }

  if (WiFi.status() == WL_CONNECTED) {
    Serial.println("[WiFi] Connected!");
    Serial.print("[WiFi] IP address: ");
    Serial.println(WiFi.localIP());
  }
  
  initTime();
  
  server.on("/status", HTTP_GET, handleStatus);
  server.on("/on", HTTP_PUT, handleOn);
  server.on("/off", HTTP_PUT, handleOff);
  server.on("/ha-hook-url", HTTP_PUT, handleSetWebhook);
  server.on("/synctime", HTTP_PUT, handleSyncTime);
  server.on("/schedule", HTTP_PUT, handlePutSchedule);
  server.on("/schedule", HTTP_DELETE, handleDeleteSchedule);
  server.on("/journal", HTTP_GET, handleGetJournal);
  server.on("/journal", HTTP_DELETE, handleDeleteJournal);
  server.on("/state-journal", HTTP_GET, handleGetStateJournal);
  server.on("/state-journal", HTTP_DELETE, handleDeleteStateJournal);
  server.onNotFound(handleNotFound);
  
  server.begin();
  Serial.println();
  Serial.print("[HTTP] Server started on port ");
  Serial.println(HTTP_PORT);
  Serial.println();

  // Initialize the state monitoring
  lastKnownAcState = isAcOn();
  lastStateCheckMillis = millis();
}

void loop() {
  ledSence.update();
  server.handleClient();
  checkSchedules();
  checkForExternalStateChange();
  checkWiFiConnection();
  delay(20);
}

//http://192.168.4.199:8123/api/webhook/ac_status_main
//curl -X PUT "http://192.168.4.120/ha-hook-url?value=http://192.168.4.199:8123/api/webhook/ac_status_main"
//curl -X PUT "http://192.168.4.120/schedule?id=1&hour=7&minute=0&switch=0"
//curl "http://192.168.4.120/state-journal"

//192.168.4.136
//curl -X PUT "http://192.168.4.136/ha-hook-url?value=http://192.168.4.199:8123/api/webhook/ac_status_lower"

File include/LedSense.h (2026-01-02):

#pragma once

#include <Arduino.h>

class LedSense {
public:
  LedSense() = default;

  inline void begin(uint8_t pin) {
    cfg_.pin = pin;

    filteredOn_ = false;
    acc_ = 0;
    lastSampleMs_ = millis();

    wait(cfg_.primeMs);
  }

  inline void update() {
    const uint32_t now = millis();
    if (now - lastSampleMs_ < cfg_.samplePeriodMs) return;
    lastSampleMs_ = now;

    const bool rawOn = digitalRead(cfg_.pin) == LOW;

    if (rawOn) {
      acc_ = (acc_ > static_cast<uint8_t>(255 - cfg_.stepUp)) ? 255 : static_cast<uint8_t>(acc_ + cfg_.stepUp);
    } else {
      acc_ = (acc_ < cfg_.stepDown) ? 0 : static_cast<uint8_t>(acc_ - cfg_.stepDown);
    }

    // Hysteresis thresholds
    if (!filteredOn_ && acc_ >= cfg_.onThreshold) filteredOn_ = true;
    if ( filteredOn_ && acc_ <= cfg_.offThreshold) filteredOn_ = false;
  }

  bool isOn() const { return filteredOn_; }

  inline void wait(uint32_t durationMs) {
    const uint32_t start = millis();
    while (millis() - start < durationMs) {
      update();
      delay(1);
    }
  }

private:
  struct Config {
    uint8_t pin = 32;

    uint32_t samplePeriodMs = 10;          // how often we sample input

    uint8_t stepUp = 18;                   // accumulator increment when raw==ON
    uint8_t stepDown = 8;                  // accumulator decrement when raw==OFF

    uint8_t onThreshold = 200;             // hysteresis high threshold
    uint8_t offThreshold = 55;             // hysteresis low threshold

    uint32_t primeMs = 300;                // prime duration at begin()
  };

  Config cfg_{};

  bool filteredOn_ = false;
  uint8_t acc_ = 0;
  uint32_t lastSampleMs_ = 0;
};

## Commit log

2025-11-25 refactor removed logging and added switch retry
2026-01-02 non blocking led sense
